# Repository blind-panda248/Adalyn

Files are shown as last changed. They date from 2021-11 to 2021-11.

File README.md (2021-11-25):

# Adalyn
Case files for the Adalyn PCB. For more information see the original repo by MarvFPV: https://github.com/MarvFPV/Adalyn

Note: these are currently untested

This case is designed to accept the Adalyn PCB by Tominabox1. It utilizes a custom plate designed to mount via Geonworks Tadpoles. The top and bottom are provided as solid model files meant to be 3D Printed and accept the heatset inserts specified in the BOM below. The Plate is provided as a dxf file and is meant to be cut via laser or CNC mill. Note that laser kerf has not been accounted for.

UPDATE 11/25: Top-mount version added; substitutes tadpoles for additional M2 inserts and screws. New top and plate files to be used with existing bottom.




BOMs:

Tadpole-Mount:
| Part  | Quantity |
| --- | --- |
| Case Top (Adalyn Top.stl) | 1 |
| Case Bottom (Adalyn Bottom.stl) | 1  |
| Plate (Adalyn Plate.dxf) | 1  |
| PCB (Not provided) | 1  |
| Geonworks Tadpoles | 8  |
| Tapered M2 Heatset inserts (McMaster 94180A312) | 7  |
| M2 screws (Min. shaft length 4mm, max 7.5mm) | 7  |

Top-Mount:
| Part  | Quantity |
| --- | --- |
| Case Top (Adalyn Top - Top Mount.stl) | 1 |
| Case Bottom (Adalyn Bottom.stl) | 1  |
| Plate (Adalyn Plate - Top Mount.dxf) | 1  |
| PCB (Not provided) | 1  |
| Tapered M2 Heatset inserts (McMaster 94180A312) | 15  |
| M2 screws (Min. shaft length 4mm, max 7.5mm) | 15  |

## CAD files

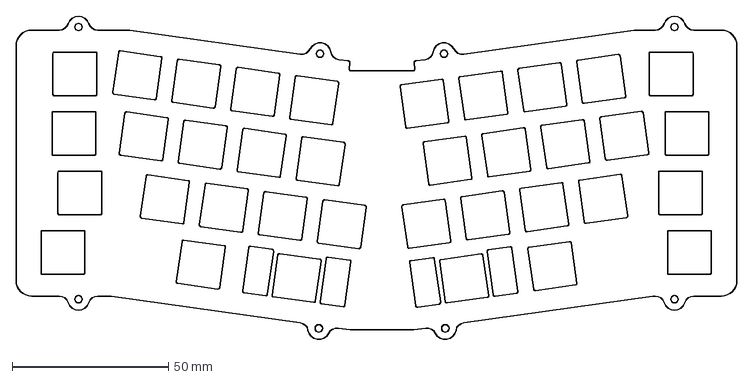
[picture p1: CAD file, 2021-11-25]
Adalyn Plate - Top Mount.DXF
230.8 x 103.7 mm

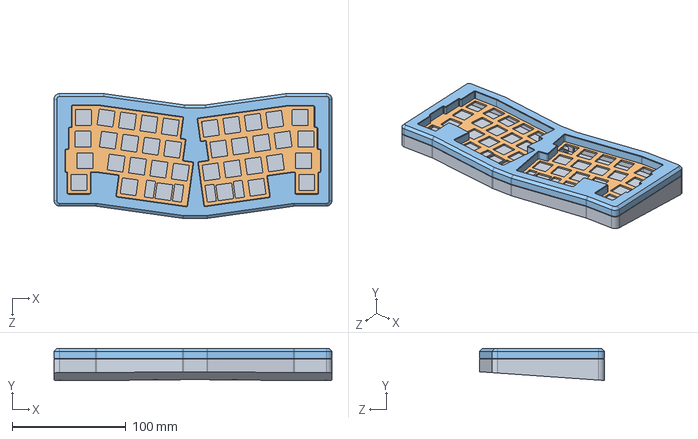
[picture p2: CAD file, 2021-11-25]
Adalyn - Top Mount.STEP
244.8 x 28.2 x 109.9 mm

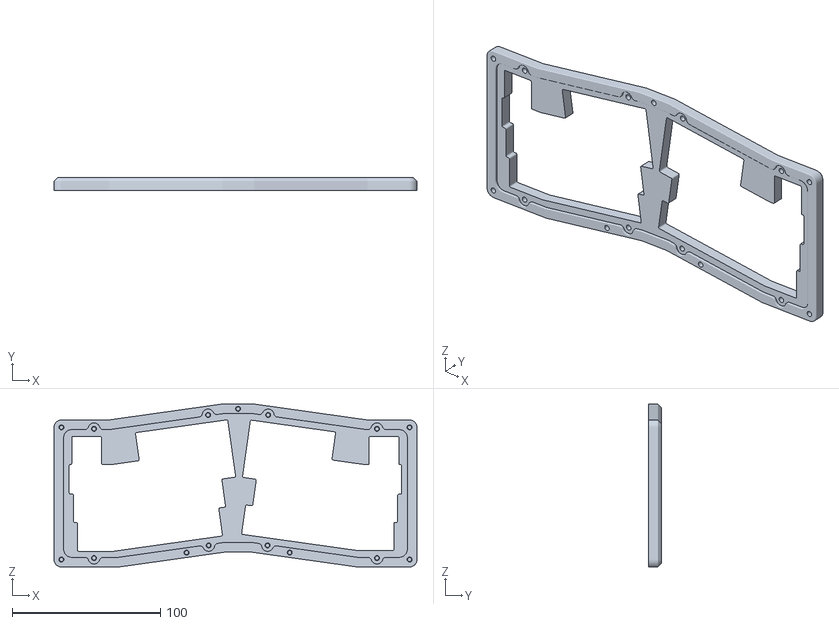
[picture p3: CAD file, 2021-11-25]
Adalyn Top - Top Mount.STL
244.8 x 9.00 x 109.9

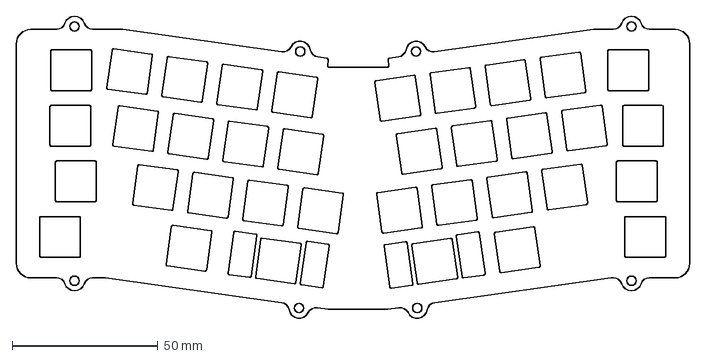
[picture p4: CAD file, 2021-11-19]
Adalyn Plate.DXF
230.8 x 103.7 mm

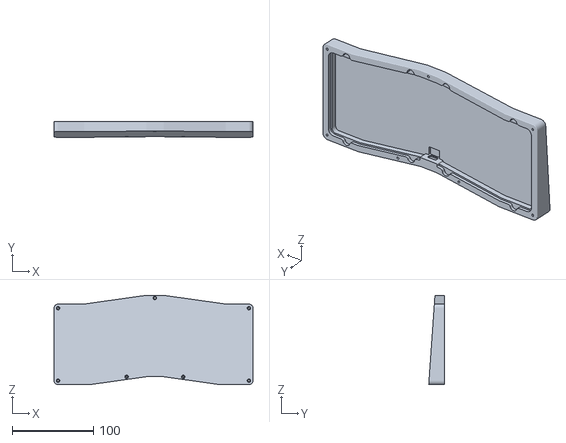
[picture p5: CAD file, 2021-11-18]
Adalyn Bottom.STL
244.8 x 19.2 x 109.9

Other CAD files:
Adalyn Top.STL
Adalyn.STEP

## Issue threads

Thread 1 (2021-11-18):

Tadpole hole ID

blind-panda248, 2021-11-18:
Tadpole holes are too tight; printing a test piece with various hole diameters to determine ideal size

Closed 2021-11-19.

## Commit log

2021-11-17 Add files via upload
    Stab cutouts added to plate
    [Adalyn Plate.DXF]
2021-11-17 Add files via upload
    Step file updated to reflect updated plate (stab cutouts added)
    [Adalyn.STEP]
2021-11-18 Add files via upload
    Bottom and Plate updated based on finalized PCB step file.
    Assembly step file updated to reflect these changes.
    [Adalyn Bottom.STL, Adalyn Plate.DXF, Adalyn.STEP]
2021-11-19 Add files via upload
    Plate and top updated tadpole holes from 3mm OD to 3.2mm.
    Step file updated to reflect updated components.
    [Adalyn Plate.DXF, Adalyn Top.STL, Adalyn.STEP]
2021-11-25 Add files via upload
    Top and Plate updated to use M2 screws/inserts for top-mount. Works with existing bottom.
    [Adalyn - Top Mount.STEP, Adalyn Plate - Top Mount.DXF, Adalyn Top - Top Mount.STL]
